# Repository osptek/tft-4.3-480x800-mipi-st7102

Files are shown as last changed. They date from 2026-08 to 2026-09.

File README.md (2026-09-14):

<p align="left">OSPTEK</p>

<h1 align="center">OSPTEK 4.3″ TFT 480×800（ST7102 · MIPI）</h1>

<p align="center"><b>TFT 模组 · MIPI · ST7102 · 多版本索引</b></p>

<p align="center"><a href="./README_EN.md">English</a> | 简体中文</p>

<p align="center">
  
  
  
  
</p>

## 目录

- [说明](#说明)
- [版本一览](#版本一览)
- [YDP430BT009-V1](#ydp430bt009-v1)
- [购买链接](#购买链接)
- [技术支持](#技术支持)

---

## 说明

本仓库收录 **4.3 寸 480×800 TFT（MIPI · ST7102）** 显示模组资料。

**根目录 README 为导航页**。下表可快速浏览各版本；点击「完整资料」进入 `versions/` 下对应**料号文件夹**（产品页、规格书、示例均在该目录内）。

规格标识（仓库名）：`tft-4.3-480x800-mipi-st7102`

---

## 版本一览

| 版本 | 宣传图 | 简介 | 完整资料 |
| ---- | --- | ---- | --- |
| YDP430BT009-V1 | YDP430BT009-V1 | [简介](#ydp430bt009-v1) | [完整资料](./versions/YDP430BT009-V1/) |

---

## YDP430BT009-V1

<p align="center">YDP430BT009-V1</p>

**说明：** 带触摸（ST7123）。

完整产品页、规格书与示例：[versions/YDP430BT009-V1/](./versions/YDP430BT009-V1/)

---

## 购买链接

<p align="center">
  
  &nbsp;&nbsp;
  
</p>

**国内（淘宝）**

- 店铺：[鱼鹰光电工厂店](https://shop110742373.taobao.com/)

**海外（AliExpress）**

- 店铺：[OSPTEK Official Store](https://www.aliexpress.com/store/1105701619)

---

## 技术支持

- 技术支持 / 产品咨询：<luyu@osptek.com>
- QQ 技术交流群：**985881096**
- 公司官网：<https://osptek.com/>
- 有任何问题，都可以在本仓库 Issues 中提问

---

<p align="center"><sub>© 2026 OSPTEK 鱼鹰光电 · 本仓库资料采用 CC BY 4.0 许可</sub></p>

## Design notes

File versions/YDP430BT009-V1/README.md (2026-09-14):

<p align="left">OSPTEK</p>

<h1 align="center">OSPTEK 4.3″ TFT 480×800（ST7102 · MIPI）</h1>

<p align="center"><b>触摸 TFT 模组 · MIPI DSI · ST7102</b></p>

<p align="center"><a href="./README_EN.md">English</a> | 简体中文 · <a href="../../README.md">规格族索引</a></p>

<p align="center">
  
  
  
  
</p>

<p align="center">OSPTEK 4.3 寸 480×800 TFT MIPI 模组（ST7102）宣传图</p>

## 目录

- [产品简介](#产品简介)
- [规格参数](#规格参数)
- [示例工程](#示例工程)
- [仓库结构](#仓库结构)
- [相关资料](#相关资料)
- [购买链接](#购买链接)
- [技术支持](#技术支持)

---

## 产品简介

OSPTEK **4.3 寸 480×800 TFT** 是一款 **MIPI DSI** 接口彩色显示模组，显示驱动为 **ST7102**，触摸驱动为 **ST7123**。适合中小尺寸 HMI、手持终端与竖屏信息面板等场景。

规格标识（仓库名）：`tft-4.3-480x800-mipi-st7102`

当前模组版本：**YDP430BT009-V1**。电气与外形细节以 [`docs/YDP_430_BT_009_V1_a418b8470b.pdf`](./docs/YDP_430_BT_009_V1_a418b8470b.pdf) 为准。

## 规格参数

| 项目 | 规格 |
| ---- | ---- |
| 尺寸 | 4.3 英寸 |
| 类型 | TFT（彩色） |
| 分辨率 | 480×800 |
| 接口 | MIPI DSI |
| 驱动 IC | ST7102 |
| 触摸驱动 | ST7123 |

> 完整外形尺寸、FPC 定义、供电与时序以产品规格书 / 驱动手册为准。

## 示例工程

| 说明 | 路径 |
| ---- | ---- |
| ESP32-P4 · ST7102 MIPI + esp-lvgl-port / LVGL9 | [`examples/esp32p4-idf5_st7102-mipi_esp-lvgl-port_lvgl9/`](./examples/esp32p4-idf5_st7102-mipi_esp-lvgl-port_lvgl9/) |
| ESP32-P4 · 防撕裂 LVGL 演示 | [`examples/with-te/p4-idf_st7102-mipi_lvgl-common-demo/`](./examples/with-te/p4-idf_st7102-mipi_lvgl-common-demo/) |
| ESP32-P4 · ST7102 MIPI + SC2336 摄像头预览 | [`examples/camera/esp32p4-idf5_st7102-mipi-dsi_sc2336-mipi-csi_video-lcd-display/`](./examples/camera/esp32p4-idf5_st7102-mipi-dsi_sc2336-mipi-csi_video-lcd-display/) |
| Linux · RK3566 设备树 + ST7123 触摸参考 | [`examples/linux/`](./examples/linux/) |
| Raspberry Pi 5 · ST7102 480×800 面板驱动 / DT overlay（仅显示） | [`examples/rpi5-panel-st7102-480x800/`](./examples/rpi5-panel-st7102-480x800/) |
| Raspberry Pi 5 · ST7102 显示 + ST7123 触摸 / DT overlay | [`examples/rpi5-panel-st7102-st7123-480x800/`](./examples/rpi5-panel-st7102-st7123-480x800/) |
| Raspberry Pi 5 · ST7102 + ST7123 · LVGL（DRM + EVDEV） | [`examples/rpi5-lvgl-st7102-st7123-480x800/`](./examples/rpi5-lvgl-st7102-st7123-480x800/) |

## 仓库结构

```text
tft-4.3-480x800-mipi-st7102/                                # 仓库根（导航见 ../../README.md）
└── versions/
    └── YDP430BT009-V1/                                # 本料号完整资料
        ├── README.md
        ├── README_EN.md
        ├── images/
        ├── docs/
        └── examples/
```

## 相关资料

### 本产品资料

| 资料 | 链接 |
| ---- | ---- |
| 产品规格书（YDP430BT009-V1） | [`docs/YDP_430_BT_009_V1_a418b8470b.pdf`](./docs/YDP_430_BT_009_V1_a418b8470b.pdf) |
| 外形图（YDP430BT009-V1） | [`docs/YDP430BT009-V1_外形图.pdf`](./docs/YDP430BT009-V1_%E5%A4%96%E5%BD%A2%E5%9B%BE.pdf) |
| 3D 图纸（YDP430BT009-V1） | [`docs/YDP430BT009-V1.dwg`](./docs/YDP430BT009-V1.dwg) |
| 3D 模型（STEP） | [`docs/YDP430BT009-V1.step`](./docs/YDP430BT009-V1.step) |
| 驱动 IC 数据手册（ST7102） | [`docs/ST7102_Datasheet_V0.22.pdf`](./docs/ST7102_Datasheet_V0.22.pdf) |
| 初始化序列（C） | [`docs/GX09C_ST7102+BOE4.3_2LANE_90HZ.c`](./docs/GX09C_ST7102+BOE4.3_2LANE_90HZ.c) |
| 时序配置参考图（90 Hz） | [`docs/RGB_Output_Timing_90Hz.jpg`](./docs/RGB_Output_Timing_90Hz.jpg) |
| 4.3 寸 LCD 转接板原理图 | [`docs/4.3寸LCD转接板V1.0.pdf`](./docs/4.3%E5%AF%B8LCD%E8%BD%AC%E6%8E%A5%E6%9D%BFV1.0.pdf) |

### 示例工程

- [ESP32-P4 ST7102 MIPI + LVGL9](./examples/esp32p4-idf5_st7102-mipi_esp-lvgl-port_lvgl9/)
- [ESP32-P4 防撕裂 LVGL 演示](./examples/with-te/p4-idf_st7102-mipi_lvgl-common-demo/)
- [ESP32-P4 ST7102 MIPI + SC2336 摄像头预览](./examples/camera/esp32p4-idf5_st7102-mipi-dsi_sc2336-mipi-csi_video-lcd-display/)
- [Linux RK3566 + ST7123 参考](./examples/linux/)
- [Raspberry Pi 5 ST7102 面板（仅显示）](./examples/rpi5-panel-st7102-480x800/)
- [Raspberry Pi 5 ST7102 显示 + ST7123 触摸](./examples/rpi5-panel-st7102-st7123-480x800/)
- [Raspberry Pi 5 ST7102 + ST7123 · LVGL](./examples/rpi5-lvgl-st7102-st7123-480x800/)

## 购买链接

<p align="center">
  
  &nbsp;&nbsp;
  
</p>

**国内（淘宝）**

- 店铺：[鱼鹰光电工厂店](https://shop110742373.taobao.com/)

**海外（AliExpress）**

- 店铺：[OSPTEK Official Store](https://www.aliexpress.com/store/1105701619)

## 技术支持

- 技术支持 / 产品咨询：<luyu@osptek.com>
- QQ 技术交流群：**985881096**
- 公司官网：<https://osptek.com/>
- 有任何问题，都可以在本仓库 Issues 中提问

---

<p align="center"><sub>© 2026 OSPTEK 鱼鹰光电 · 本仓库资料采用 CC BY 4.0 许可</sub></p>

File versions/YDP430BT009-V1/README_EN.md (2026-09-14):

<p align="left">OSPTEK</p>

<h1 align="center">OSPTEK 4.3″ TFT 480×800 (ST7102 · MIPI)</h1>

<p align="center"><b>Touch TFT module · MIPI DSI · ST7102</b></p>

<p align="center"><a href="./README.md">简体中文</a> | English · <a href="../../README_EN.md">Family index</a></p>

<p align="center">
  
  
  
  
</p>

<p align="center">OSPTEK 4.3" 480×800 TFT MIPI module (ST7102) product image</p>

## Contents

- [Overview](#overview)
- [Specifications](#specifications)
- [Sample projects](#sample-projects)
- [Repository layout](#repository-layout)
- [Resources](#resources)
- [Buy](#buy)
- [Support](#support)

---

## Overview

OSPTEK **4.3″ 480×800 TFT** is a **MIPI DSI** color display module driven by **ST7102**, with touch controller **ST7123**. It suits compact HMI, handheld terminals, and portrait info panels.

Spec ID (repository name): `tft-4.3-480x800-mipi-st7102`

Current module version: **YDP430BT009-V1**. Electrical and mechanical details follow [`docs/YDP_430_BT_009_V1_a418b8470b.pdf`](./docs/YDP_430_BT_009_V1_a418b8470b.pdf).

## Specifications

| Item | Spec |
| ---- | ---- |
| Size | 4.3 inch |
| Type | TFT (color) |
| Resolution | 480×800 |
| Interface | MIPI DSI |
| Driver IC | ST7102 |
| Touch IC | ST7123 |

> Full outline, FPC definition, power, and timing follow the product datasheet / driver IC datasheet.

## Sample projects

| Description | Path |
| ---- | ---- |
| ESP32-P4 · ST7102 MIPI + esp-lvgl-port / LVGL9 | [`examples/esp32p4-idf5_st7102-mipi_esp-lvgl-port_lvgl9/`](./examples/esp32p4-idf5_st7102-mipi_esp-lvgl-port_lvgl9/) |
| ESP32-P4 · tear-related LVGL demo | [`examples/with-te/p4-idf_st7102-mipi_lvgl-common-demo/`](./examples/with-te/p4-idf_st7102-mipi_lvgl-common-demo/) |
| ESP32-P4 · ST7102 MIPI + SC2336 camera preview | [`examples/camera/esp32p4-idf5_st7102-mipi-dsi_sc2336-mipi-csi_video-lcd-display/`](./examples/camera/esp32p4-idf5_st7102-mipi-dsi_sc2336-mipi-csi_video-lcd-display/) |
| Linux · RK3566 device tree + ST7123 touch reference | [`examples/linux/`](./examples/linux/) |
| Raspberry Pi 5 · ST7102 480×800 panel / DT overlay (display only) | [`examples/rpi5-panel-st7102-480x800/`](./examples/rpi5-panel-st7102-480x800/) |
| Raspberry Pi 5 · ST7102 display + ST7123 touch / DT overlay | [`examples/rpi5-panel-st7102-st7123-480x800/`](./examples/rpi5-panel-st7102-st7123-480x800/) |
| Raspberry Pi 5 · ST7102 + ST7123 · LVGL (DRM + EVDEV) | [`examples/rpi5-lvgl-st7102-st7123-480x800/`](./examples/rpi5-lvgl-st7102-st7123-480x800/) |

## Repository layout

```text
tft-4.3-480x800-mipi-st7102/                                # repo root (nav: ../../README_EN.md)
└── versions/
    └── YDP430BT009-V1/                                # full materials for this part number
        ├── README.md
        ├── README_EN.md
        ├── images/
        ├── docs/
        └── examples/
```

## Resources

### Product files

| Resource | Link |
| ---- | ---- |
| Product datasheet (YDP430BT009-V1) | [`docs/YDP_430_BT_009_V1_a418b8470b.pdf`](./docs/YDP_430_BT_009_V1_a418b8470b.pdf) |
| Outline drawing (YDP430BT009-V1) | [`docs/YDP430BT009-V1_外形图.pdf`](./docs/YDP430BT009-V1_%E5%A4%96%E5%BD%A2%E5%9B%BE.pdf) |
| 3D drawing (YDP430BT009-V1) | [`docs/YDP430BT009-V1.dwg`](./docs/YDP430BT009-V1.dwg) |
| 3D model (STEP) | [`docs/YDP430BT009-V1.step`](./docs/YDP430BT009-V1.step) |
| Driver IC datasheet (ST7102) | [`docs/ST7102_Datasheet_V0.22.pdf`](./docs/ST7102_Datasheet_V0.22.pdf) |
| Init sequence (C) | [`docs/GX09C_ST7102+BOE4.3_2LANE_90HZ.c`](./docs/GX09C_ST7102+BOE4.3_2LANE_90HZ.c) |
| Timing reference (90 Hz) | [`docs/RGB_Output_Timing_90Hz.jpg`](./docs/RGB_Output_Timing_90Hz.jpg) |
| 4.3″ LCD adapter schematic | [`docs/4.3寸LCD转接板V1.0.pdf`](./docs/4.3%E5%AF%B8LCD%E8%BD%AC%E6%8E%A5%E6%9D%BFV1.0.pdf) |

### Samples

- [ESP32-P4 ST7102 MIPI + LVGL9](./examples/esp32p4-idf5_st7102-mipi_esp-lvgl-port_lvgl9/)
- [ESP32-P4 tear-related LVGL demo](./examples/with-te/p4-idf_st7102-mipi_lvgl-common-demo/)
- [ESP32-P4 ST7102 MIPI + SC2336 camera preview](./examples/camera/esp32p4-idf5_st7102-mipi-dsi_sc2336-mipi-csi_video-lcd-display/)
- [Linux RK3566 + ST7123 reference](./examples/linux/)
- [Raspberry Pi 5 ST7102 panel (display only)](./examples/rpi5-panel-st7102-480x800/)
- [Raspberry Pi 5 ST7102 display + ST7123 touch](./examples/rpi5-panel-st7102-st7123-480x800/)
- [Raspberry Pi 5 ST7102 + ST7123 · LVGL](./examples/rpi5-lvgl-st7102-st7123-480x800/)

## Buy

<p align="center">
  
  &nbsp;&nbsp;
  
</p>

**Overseas (AliExpress)**

- Store: [OSPTEK Official Store](https://www.aliexpress.com/store/1105701619)

**China (Taobao)**

- Store: [鱼鹰光电工厂店](https://shop110742373.taobao.com/)

## Support

- Technical support / product inquiry: <luyu@osptek.com>
- QQ group (China): **985881096**
- Website: <https://osptek.com/>
- Feel free to open an Issue in this repository if you have any questions

---

<p align="center"><sub>© 2026 OSPTEK · Materials in this repository are licensed under CC BY 4.0</sub></p>

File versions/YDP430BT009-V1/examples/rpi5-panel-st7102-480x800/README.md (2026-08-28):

# Raspberry Pi 5 · ST7102 480×800（仅显示）

本目录为 **YDP430BT009-V1** 在 Raspberry Pi 5 上的 **仅显示** 内核模块与 DT overlay 示例（无触摸）。

本目录文件：

| 文件 | 说明 |
| ---- | ---- |
| `panel-st7102-480x800.c` | ST7102 DRM panel 驱动 |
| `Makefile` | 内核模块编译 |
| `vc4-kms-dsi-st7102-480x800.dts` | DSI overlay |

---

# 1. 准备工作

```bash
sudo apt update
sudo apt install build-essential linux-headers-$(uname -r) device-tree-compiler
```

将本目录拷到树莓派后进入该目录（以下命令默认在本目录执行）。

# 2. 编译内核模块

```bash
make clean
make
```

# 3. 编译并安装 Overlay / 模块

```bash
dtc -@ -I dts -O dtb -o vc4-kms-dsi-st7102-480x800.dtbo vc4-kms-dsi-st7102-480x800.dts
sudo cp vc4-kms-dsi-st7102-480x800.dtbo /boot/firmware/overlays/
sudo mkdir -p /lib/modules/$(uname -r)/kernel/drivers/gpu/drm/panel/
sudo cp panel-st7102-480x800.ko /lib/modules/$(uname -r)/kernel/drivers/gpu/drm/panel/
sudo depmod -a
```

> Overlay 必须使用 `dtc -@`，否则符号修复可能失败，DTO 无法正确加载。

# 4. 启用

编辑 `/boot/firmware/config.txt`：

```bash
sudo nano /boot/firmware/config.txt
```

添加（或确认）如下配置：

```text
# 关闭自动检测，避免和手动 overlay 冲突
display_auto_detect=0

dtoverlay=vc4-kms-v3d

dtoverlay=vc4-kms-dsi-st7102-480x800

# 忽略官方 LCD
ignore_lcd=1
```

重启：

```bash
sudo reboot
```

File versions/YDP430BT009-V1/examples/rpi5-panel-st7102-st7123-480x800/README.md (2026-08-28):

# Raspberry Pi 5 · ST7102 显示 + ST7123 触摸（480×800）

本目录为 **YDP430BT009-V1** 在 Raspberry Pi 5 上的 **显示 + 触摸** 内核模块与 DT overlay 示例。

本目录文件：

| 文件 | 说明 |
| ---- | ---- |
| `panel-st7102-480x800.c` | ST7102 DRM panel 驱动 |
| `st7123_touch.c` | ST7123 触摸驱动 |
| `Makefile` | 内核模块编译 |
| `vc4-kms-dsi-st7102-480x800-st7123-overlay.dts` | DSI + 触摸 overlay |

若还需跑 LVGL，见同级目录 [`../rpi5-lvgl-st7102-st7123-480x800/`](../rpi5-lvgl-st7102-st7123-480x800/)。

---

# 1. 准备工作

```bash
sudo apt update
sudo apt install build-essential linux-headers-$(uname -r) device-tree-compiler
```

将本目录拷到树莓派后进入该目录（以下命令默认在本目录执行）。

# 2. 编译内核模块

```bash
make clean
make
```

# 3. 安装模块

```bash
sudo mkdir -p /lib/modules/$(uname -r)/kernel/drivers/gpu/drm/panel/
sudo cp panel-st7102-480x800.ko /lib/modules/$(uname -r)/kernel/drivers/gpu/drm/panel/

sudo mkdir -p /lib/modules/$(uname -r)/kernel/drivers/input/touchscreen/
sudo cp st7123_touch.ko /lib/modules/$(uname -r)/kernel/drivers/input/touchscreen/

sudo depmod -a
```

设置开机自动加载模块：编辑 `/etc/modules`，末尾加上：

```text
panel-st7102-480x800
st7123_touch
```

# 4. 编译并安装 Overlay

```bash
dtc -@ -I dts -O dtb -o vc4-kms-dsi-st7102-480x800-st7123-overlay.dtbo vc4-kms-dsi-st7102-480x800-st7123-overlay.dts
sudo cp vc4-kms-dsi-st7102-480x800-st7123-overlay.dtbo /boot/firmware/overlays/
```

> Overlay 必须使用 `dtc -@`，否则符号修复可能失败，DTO 无法正确加载。

# 5. 启用

编辑 `/boot/firmware/config.txt`：

```bash
sudo nano /boot/firmware/config.txt
```

添加（或确认）：

```text
# 关闭自动检测，避免和手动 overlay 冲突
display_auto_detect=0

dtoverlay=vc4-kms-v3d

# 启用 ST7102 显示与 ST7123 触控 Overlay
dtoverlay=vc4-kms-dsi-st7102-480x800-st7123-overlay

# 忽略官方 LCD
ignore_lcd=1
```

重启：

```bash
sudo reboot
```

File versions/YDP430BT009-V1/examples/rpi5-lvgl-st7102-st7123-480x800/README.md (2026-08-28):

# Raspberry Pi 5 · ST7102 + ST7123 · LVGL（480×800）

本目录为 **YDP430BT009-V1** 在 Raspberry Pi 5 上跑 **LVGL（lv_port_linux / DRM + EVDEV）** 的参考：含显示/触摸内核模块、DT overlay，以及替换 `lv_port_linux` 用的 `main.c`。

本目录文件：

| 文件 | 说明 |
| ---- | ---- |
| `panel-st7102-480x800.c` | ST7102 DRM panel 驱动 |
| `st7123_touch.c` | ST7123 触摸驱动 |
| `Makefile` | 内核模块编译 |
| `vc4-kms-dsi-st7102-480x800-st7123-overlay.dts` | DSI + 触摸 overlay |
| `main.c` | 拷入 `lv_port_linux/src/main.c` 的参考实现（默认 480×800 / DRM / EVDEV） |

仅点亮显示+触摸、不跑 LVGL 时，也可只用同级 [`../rpi5-panel-st7102-st7123-480x800/`](../rpi5-panel-st7102-st7123-480x800/)。

---

# 1. 准备工作

```bash
sudo apt update
sudo apt install build-essential linux-headers-$(uname -r) device-tree-compiler
```

将本目录拷到树莓派后进入该目录。

# 2. 编译并安装内核模块

```bash
make clean
make

sudo mkdir -p /lib/modules/$(uname -r)/kernel/drivers/gpu/drm/panel/
sudo cp panel-st7102-480x800.ko /lib/modules/$(uname -r)/kernel/drivers/gpu/drm/panel/

sudo mkdir -p /lib/modules/$(uname -r)/kernel/drivers/input/touchscreen/
sudo cp st7123_touch.ko /lib/modules/$(uname -r)/kernel/drivers/input/touchscreen/

sudo depmod -a
```

开机自动加载：编辑 `/etc/modules`，末尾加上：

```text
panel-st7102-480x800
st7123_touch
```

# 3. 编译并安装 Overlay

```bash
dtc -@ -I dts -O dtb -o vc4-kms-dsi-st7102-480x800-st7123-overlay.dtbo vc4-kms-dsi-st7102-480x800-st7123-overlay.dts
sudo cp vc4-kms-dsi-st7102-480x800-st7123-overlay.dtbo /boot/firmware/overlays/
```

> Overlay **必须**使用 `dtc -@`，否则符号修复可能失败，DTO 无法正确加载。

# 4. 启用 Overlay

编辑 `/boot/firmware/config.txt`：

```bash
sudo nano /boot/firmware/config.txt
```

```text
# 关闭自动检测，避免和手动 overlay 冲突
display_auto_detect=0

dtoverlay=vc4-kms-v3d

# 启用 ST7102 显示与 ST7123 触控 Overlay
dtoverlay=vc4-kms-dsi-st7102-480x800-st7123-overlay

# 忽略官方 LCD
ignore_lcd=1
```

```bash
sudo reboot
```

# 5. 关闭桌面（若有桌面；无桌面可跳过）

## 5.1 开机进入命令行

```bash
sudo raspi-config
```

- `1 System Options` → `S5 Boot` → 选 **Console**
- `1 System Options` → `S6 Auto Login`：按需要选择是否自动登录
- 退出后重启：`sudo reboot`

## 5.2 用户组权限

```bash
sudo usermod -aG video,input,render $USER
```

重新登录或重启后生效。

# 6. 安装并运行 LVGL（lv_port_linux）

## 6.1 依赖

```bash
sudo apt install \
  build-essential cmake python3 python3-venv ninja-build \
  libsdl2-dev \
  libwayland-dev libxkbcommon-dev wayland-protocols \
  libx11-dev \
  libdrm-dev libgbm-dev \
  libevdev-dev \
  libwebp-dev \
  libegl-dev libgles-dev libgl-dev
```

## 6.2 克隆

```bash
git clone -b release/v9.5 --recursive https://github.com/lvgl/lv_port_linux.git
cd lv_port_linux
```

## 6.3 修改 `lv_conf.defaults`

```bash
nano lv_conf.defaults
```

确保包含（或等价配置）：

```text
LV_COLOR_DEPTH               32
LV_USE_LINUX_FBDEV           0
LV_USE_LINUX_DRM             1
LV_USE_LINUX_DRM_GBM_BUFFERS 0
LV_USE_EVDEV                 1
LV_USE_DEMO_WIDGETS          1
```

## 6.4 确认 DRM / 触摸节点

DRM（找 `status` 为 `connected` 的 DSI）：

```bash
for file in /sys/class/drm/card*-*/status; do echo "$file -> $(cat $file)"; done
```

示例：`/sys/class/drm/card2-DSI-2/status -> connected` → 设备节点多为 **`/dev/dri/card2`**（以实机为准）。

触摸：

```bash
cat /proc/bus/input/devices
```

查找 `ST7123` / `st7123`，在 `Handlers=` 中取 `eventN`，例如 `event5` → **`/dev/input/event5`**（以实机为准）。

## 6.5 替换 `src/main.c`

将本目录 `main.c` 拷到 `lv_port_linux/src/main.c`。若实机 DRM/触摸节点不是 `card2` / `event5`，请改 `main.c` 里：

- `LV_LINUX_DRM_CARD`
- `LV_LINUX_EVDEV_POINTER_DEVICE`

（默认分辨率已按 **480×800** 配置。）

## 6.6 若构建未生成 `lv_conf.h`

参见上游说明：<https://github.com/lvgl/lv_port_linux/issues/127>  
可在 CMake 中确保：

```cmake
find_package(Python3 REQUIRED COMPONENTS Interpreter)
```

## 6.7 编译与运行

```bash
cd lv_port_linux
cmake -B build -GNinja
cmake --build build
./build/bin/lvglsim
```

# 7. 开机自启（可选，systemd）

```bash
sudo nano /etc/systemd/system/lvgl.service
```

按实际用户与路径修改：

```ini
[Unit]
Description=LVGL Application Service
After=multi-user.target
Wants=multi-user.target

[Service]
Type=simple
User=pi
WorkingDirectory=/home/pi/lv_port_linux
ExecStart=/home/pi/lv_port_linux/build/bin/lvglsim
Restart=always
RestartSec=3
StandardOutput=journal
StandardError=journal

[Install]
WantedBy=multi-user.target
```

```bash
sudo usermod -aG render,video,input pi
sudo systemctl daemon-reload
sudo systemctl start lvgl.service
sudo systemctl status lvgl.service
# 确认正常后再：
sudo systemctl enable lvgl.service
```

常用：

```bash
sudo journalctl -u lvgl.service -f
sudo systemctl stop lvgl.service
sudo systemctl disable lvgl.service
```

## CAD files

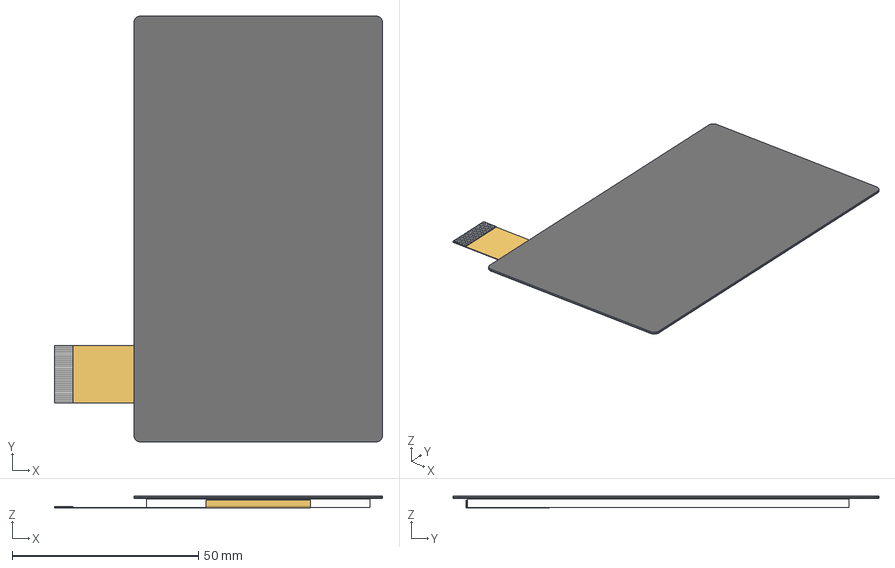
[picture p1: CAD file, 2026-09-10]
versions/YDP430BT009-V1/docs/YDP430BT009-V1.step
88.1 x 114.4 x 3.32 mm

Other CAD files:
versions/YDP430BT009-V1/docs/YDP430BT009-V1.dwg

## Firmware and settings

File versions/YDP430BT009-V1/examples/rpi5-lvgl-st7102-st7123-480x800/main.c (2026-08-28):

/*******************************************************************
 *
 * main.c - LVGL runner for Raspberry Pi 5 (Linux DRM + EVDEV)
 *
 * Modified for ST7102 DSI Screen (480x800) and Sitronix ST7123 Touch (/dev/input/event5)
 *
 ******************************************************************/
#include <unistd.h>
#include <pthread.h>
#include <stdio.h>
#include <stdlib.h>
#include <string.h>

#include "lvgl/lvgl.h"
#include "lvgl/demos/lv_demos.h"

#include "src/lib/driver_backends.h"
#include "src/lib/simulator_util.h"
#include "src/lib/simulator_settings.h"

/* Internal functions */
static void configure_simulator(int argc, char ** argv);
static void print_lvgl_version(void);
static void print_usage(void);

/* contains the name of the selected backend if user
 * has specified one on the command line */
static char * selected_backend;

/* Global simulator settings, defined in lv_linux_backend.c */
extern simulator_settings_t settings;


/**
 * @brief Print LVGL version
 */
static void print_lvgl_version(void)
{
    fprintf(stdout, "%d.%d.%d-%s\n",
            LVGL_VERSION_MAJOR,
            LVGL_VERSION_MINOR,
            LVGL_VERSION_PATCH,
            LVGL_VERSION_INFO);
}

/**
 * @brief Print usage information
 */
static void print_usage(void)
{
    fprintf(stdout,
            "\nlvglsim [-V] [-B] [-f] [-m] [-b backend_name] [-W window_width] [-H window_height] [-R rotation]\n\n");
    fprintf(stdout, "-V print LVGL version\n");
    fprintf(stdout, "-B list supported backends\n");
    fprintf(stdout, "-f fullscreen\n");
    fprintf(stdout, "-m maximize\n");
}

/**
 * @brief Configure simulator
 * @description process arguments received by the program to select
 * appropriate options
 * @param argc the count of arguments in argv
 * @param argv The arguments
 */
static void configure_simulator(int argc, char ** argv)
{
    int opt = 0;

    selected_backend = NULL;
    driver_backends_register();

    const char * env_w = getenv("LV_SIM_WINDOW_WIDTH");
    const char * env_h = getenv("LV_SIM_WINDOW_HEIGHT");
    
    /* 针对 480x800 ST7102 面板的默认分辨率配置 */
    settings.window_width = atoi(env_w ? env_w : "480");
    settings.window_height = atoi(env_h ? env_h : "800");

    /* Parse the command-line options. */
    while((opt = getopt(argc, argv, "b:fmW:H:R:BVh")) != -1) {
        switch(opt) {
            case 'h':
                print_usage();
                exit(EXIT_SUCCESS);
                break;
            case 'V':
                print_lvgl_version();
                exit(EXIT_SUCCESS);
                break;
            case 'B':
                driver_backends_print_supported();
                exit(EXIT_SUCCESS);
                break;
            case 'b':
                if(driver_backends_is_supported(optarg) == 0) {
                    die("error no such backend: %s\n", optarg);
                }
                selected_backend = strdup(optarg);
                break;
            case 'f':
                settings.fullscreen = true;
                break;
            case 'm':
                settings.maximize = true;
                break;
            case 'W':
                settings.window_width = atoi(optarg);
                break;
            case 'H':
                settings.window_height = atoi(optarg);
                break;
            case 'R':
                switch(atoi(optarg)) {
                    case 0:
                        settings.rotation = LV_DISPLAY_ROTATION_0;
                        break;
                    case 90:
                        settings.rotation = LV_DISPLAY_ROTATION_90;
                        break;
                    case 180:
                        settings.rotation = LV_DISPLAY_ROTATION_180;
                        break;
                    case 270:
                        settings.rotation = LV_DISPLAY_ROTATION_270;
                        break;
                    default:
                        LV_LOG_WARN("Invalid rotation angle. Valid angles are {0, 90, 180, 270}");
                        break;
                }
                break;
            case ':':
                print_usage();
                die("Option -%c requires an argument.\n", optopt);
                break;
            case '?':
                print_usage();
                die("Unknown option -%c.\n", optopt);
        }
    }
}

/**
 * @brief entry point
 * @description start a demo
 * @param argc the count of arguments in argv
 * @param argv The arguments
 */
int main(int argc, char ** argv)
{
    configure_simulator(argc, argv);

    /* Initialize LVGL. */
    lv_init();

    /* 1. 显式指定树莓派 5 默认后端的环境变量（如果没有通过 -b 指定） */
    if(selected_backend == NULL) {
        selected_backend = "DRM";
    }

    /* 2. 覆盖设置 DRM 显卡设备节点为树莓派 5 的 MIPI-DSI 卡节点 (/dev/dri/card2) */
    setenv("LV_LINUX_DRM_CARD", "/dev/dri/card2", 1);

    /* 初始化 DRM 显示后端 */
    if(driver_backends_init_backend(selected_backend) == -1) {
        die("Failed to initialize display backend");
    }

    if(settings.rotation) {
#if LV_USE_DRAW_NANOVG && LV_DRAW_TRANSFORM_USE_MATRIX
        lv_display_set_matrix_rotation(NULL, true);
#endif
        lv_display_set_rotation(NULL, settings.rotation);
    }

    /* 3. 配置 EVDEV 触摸设备节点为 Sitronix ST7123 的 /dev/input/event5 */
#if LV_USE_EVDEV
    setenv("LV_LINUX_EVDEV_POINTER_DEVICE", "/dev/input/event5", 1);
    if(driver_backends_init_backend("EVDEV") == -1) {
        die("Failed to initialize evdev");
    }
#endif

    /* 4. 创建及启动 Demo */
    lv_demo_widgets();

    /* 隐藏触摸设备绑定的鼠标光标/箭头 */
    lv_indev_t * indev = lv_indev_get_next(NULL);
    while(indev) {
        if(lv_indev_get_type(indev) == LV_INDEV_TYPE_POINTER) {
            lv_obj_t * cursor = lv_indev_get_cursor(indev);
            if(cursor) {
                lv_obj_add_flag(cursor, LV_OBJ_FLAG_HIDDEN);
            }
        }
        indev = lv_indev_get_next(indev);
    }

    /* 5. 进入主运行循环 */
    driver_backends_run_loop();

    return 0;
}

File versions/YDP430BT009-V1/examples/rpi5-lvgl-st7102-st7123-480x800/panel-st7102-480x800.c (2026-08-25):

/*
 * ST7102 480x800 2-Lane MIPI-DSI Panel Driver for Raspberry Pi 5
 *
 * This example is from the open-source sharing by engineers of Yuying Optoelectronics (鱼鹰光电)
 * on Github.com/osptek. Welcome to provide improvement suggestions.
 *
 * 本例程来源于鱼鹰光电的工程师的开源分享 Github.com/osptek，欢迎提出改进意见
 */
 
#include <drm/drm_mipi_dsi.h>
#include <drm/drm_modes.h>
#include <drm/drm_panel.h>
#include <linux/backlight.h>
#include <linux/delay.h>
#include <linux/gpio/consumer.h>
#include <linux/module.h>
#include <linux/of.h>
#include <video/mipi_display.h>

struct power_on_timing {
	unsigned long post_reset;
	unsigned long reset_low;
	unsigned long after_reset;
	unsigned long slpout;
};

struct st7102_desc {
	const struct drm_display_mode *mode;
	unsigned int lanes;
	unsigned long flags;
	enum mipi_dsi_pixel_format format;
	int (*init_sequence)(struct mipi_dsi_device *dsi);
	const struct power_on_timing *pwr_timing;
	bool do_sw_reset;
};

struct st7102 {
	struct drm_panel panel;
	struct mipi_dsi_device *dsi;
	const struct st7102_desc *desc;
	struct gpio_desc *reset;
	enum drm_panel_orientation orientation;
};

static inline struct st7102 *to_st7102(struct drm_panel *panel)
{
	return container_of(panel, struct st7102, panel);
}

static int st7102_480x800_init_sequence(struct mipi_dsi_device *dsi)
{
	struct mipi_dsi_multi_context ctx = { .dsi = dsi };

	mipi_dsi_dcs_write_seq_multi(&ctx, 0x99, 0x71, 0x02, 0xa2);
	mipi_dsi_dcs_write_seq_multi(&ctx, 0x99, 0x71, 0x02, 0xa3);
	mipi_dsi_dcs_write_seq_multi(&ctx, 0x99, 0x71, 0x02, 0xa4);
	mipi_dsi_dcs_write_seq_multi(&ctx, 0xB0, 0x22, 0x57, 0x1E, 0x61, 0x2F, 0x57, 0x61);
	mipi_dsi_dcs_write_seq_multi(&ctx, 0xB7, 0x64, 0x64);
	mipi_dsi_dcs_write_seq_multi(&ctx, 0xBF, 0xB4, 0xB4);

	mipi_dsi_dcs_write_seq_multi(&ctx, 0xC8,
		0x00, 0x00, 0x13, 0x24, 0x44, 0x00, 0x74, 0x03, 0xB8, 0x04,
		0x11, 0x16, 0x08, 0x86, 0x04, 0x21, 0xD3, 0x02, 0x10, 0x0F,
		0x22, 0x4D, 0x0E, 0x90, 0x09, 0x32, 0xF0, 0x0B, 0x40, 0x0E,
		0xF3, 0x7D, 0x0E, 0xA9, 0xBF, 0x03, 0xC4);

	mipi_dsi_dcs_write_seq_multi(&ctx, 0xC9,
		0x00, 0x00, 0x13, 0x24, 0x44, 0x00, 0x74, 0x03, 0xB8, 0x04,
		0x11, 0x16, 0x08, 0x86, 0x04, 0x21, 0xD3, 0x02, 0x10, 0x0F,
		0x22, 0x4D, 0x0E, 0x90, 0x09, 0x32, 0xF0, 0x0B, 0x40, 0x0E,
		0xF3, 0x7D, 0x0E, 0xA9, 0xBF, 0x03, 0xC4);

	mipi_dsi_dcs_write_seq_multi(&ctx, 0xD7, 0x10, 0x0C, 0x36, 0x19, 0x90, 0x90);

	mipi_dsi_dcs_write_seq_multi(&ctx, 0xA3,
		0x51, 0x03, 0x80, 0xCF, 0x44, 0x00, 0x00, 0x00, 0x00, 0x04,
		0x78, 0x78, 0x00, 0x1A, 0x00, 0x45, 0x05, 0x00, 0x00, 0x00,
		0x00, 0x46, 0x00, 0x00, 0x02, 0x20, 0x52, 0x00, 0x05, 0x00,
		0x00, 0xFF);

	mipi_dsi_dcs_write_seq_multi(&ctx, 0xA6,
		0x02, 0x00, 0x24, 0x55, 0x35, 0x00, 0x38, 0x00, 0x78, 0x78,
		0x00, 0x24, 0x55, 0x36, 0x00, 0x37, 0x00, 0x78, 0x78, 0x02,
		0xAC, 0x51, 0x3A, 0x00, 0x00, 0x00, 0x78, 0x78, 0x03, 0xAC,
		0x21, 0x00, 0x04, 0x00, 0x00, 0x78, 0x78, 0x3e, 0x00, 0x06,
		0x00, 0x00, 0x00, 0x00);

	mipi_dsi_dcs_write_seq_multi(&ctx, 0xA7,
		0x19, 0x19, 0x00, 0x64, 0x40, 0x07, 0x16, 0x40, 0x00, 0x04,
		0x03, 0x78, 0x78, 0x00, 0x64, 0x40, 0x25, 0x34, 0x00, 0x00,
		0x02, 0x01, 0x78, 0x78, 0x00, 0x64, 0x40, 0x4B, 0x5A, 0x00,
		0x00, 0x02, 0x01, 0x78, 0x78, 0x00, 0x24, 0x40, 0x69, 0x78,
		0x00, 0x00, 0x00, 0x00, 0x78, 0x78, 0x00, 0x44);

	mipi_dsi_dcs_write_seq_multi(&ctx, 0xAC,
		0x08, 0x0A, 0x11, 0x00, 0x13, 0x03, 0x1B, 0x18, 0x06, 0x1A,
		0x19, 0x1B, 0x1B, 0x1B, 0x18, 0x1B, 0x09, 0x0B, 0x10, 0x02,
		0x12, 0x01, 0x1B, 0x18, 0x06, 0x1A, 0x19, 0x1B, 0x1B, 0x1B,
		0x18, 0x1B, 0xFF, 0x67, 0xFF, 0x67, 0x00);

	mipi_dsi_dcs_write_seq_multi(&ctx, 0xAD, 0xCC, 0x40, 0x46, 0x11, 0x04, 0x78, 0x78);

	mipi_dsi_dcs_write_seq_multi(&ctx, 0xE8,
		0x30, 0x07, 0x00, 0x94, 0x94, 0x9C, 0x00, 0xE2, 0x04, 0x00,
		0x00, 0x00, 0x00, 0xEF);

	mipi_dsi_dcs_write_seq_multi(&ctx, 0xE7,
		0x8B, 0x3C, 0x00, 0x0C, 0xF0, 0x5D, 0x00, 0x5D, 0x00, 0x5D,
		0x00, 0x5D, 0x00, 0xFF, 0x00, 0x08, 0x7B, 0x00, 0x00, 0xC8,
		0x6A, 0x5A, 0x08, 0x1A, 0x3C, 0x00, 0x81, 0x01, 0xCC, 0x01,
		0x7F, 0xF0, 0x22);

	/* 退出 Sleep 状态，激活 TDDI 底板 */
	mipi_dsi_dcs_write_seq_multi(&ctx, 0x11);
	msleep(600);

	/* 开启显示 */
	mipi_dsi_dcs_write_seq_multi(&ctx, 0x29);
	msleep(120);

	return ctx.accum_err;
}

static int st7102_prepare(struct drm_panel *panel)
{
	struct st7102 *st7102 = to_st7102(panel);
	struct mipi_dsi_multi_context ctx = { .dsi = st7102->dsi };

	if (st7102->reset) {
		gpiod_set_value_cansleep(st7102->reset, 1);
		msleep(st7102->desc->pwr_timing->post_reset);
		gpiod_set_value_cansleep(st7102->reset, 0);
		msleep(st7102->desc->pwr_timing->reset_low);
		gpiod_set_value_cansleep(st7102->reset, 1);
		msleep(st7102->desc->pwr_timing->after_reset);
	}

	if (st7102->desc->do_sw_reset) {
		mipi_dsi_dcs_soft_reset_multi(&ctx);
		msleep(st7102->desc->pwr_timing->after_reset);
	}

	if (st7102->desc->init_sequence) {
		int ret = st7102->desc->init_sequence(st7102->dsi);
		if (ret)
			return ret;
	}

	return ctx.accum_err;
}

static int st7102_enable(struct drm_panel *panel)
{
	struct mipi_dsi_multi_context ctx = { .dsi = to_mipi_dsi_device(panel->dev) };
	mipi_dsi_dcs_set_display_on_multi(&ctx);
	return ctx.accum_err;
}

static int st7102_disable(struct drm_panel *panel)
{
	struct mipi_dsi_multi_context ctx = { .dsi = to_mipi_dsi_device(panel->dev) };
	mipi_dsi_dcs_set_display_off_multi(&ctx);
	return ctx.accum_err;
}

static int st7102_unprepare(struct drm_panel *panel)
{
	struct st7102 *st7102 = to_st7102(panel);
	struct mipi_dsi_multi_context ctx = { .dsi = st7102->dsi };

	mipi_dsi_dcs_enter_sleep_mode_multi(&ctx);
	if (st7102->reset)
		gpiod_set_value_cansleep(st7102->reset, 0);

	return ctx.accum_err;
}

static int st7102_get_modes(struct drm_panel *panel, struct drm_connector *connector)
{
	struct st7102 *st7102 = to_st7102(panel);
	struct drm_display_mode *mode;

	mode = drm_mode_duplicate(connector->dev, st7102->desc->mode);
	if (!mode)
		return -ENOMEM;

	drm_mode_set_name(mode);
	drm_mode_probed_add(connector, mode);

	connector->display_info.width_mm = mode->width_mm;
	connector->display_info.height_mm = mode->height_mm;

	drm_connector_set_orientation_from_panel(connector, panel);
	return 1;
}

static enum drm_panel_orientation st7102_get_orientation(struct drm_panel *panel)
{
	return to_st7102(panel)->orientation;
}

static const struct drm_panel_funcs st7102_funcs = {
	.prepare = st7102_prepare,
	.enable = st7102_enable,
	.disable = st7102_disable,
	.unprepare = st7102_unprepare,
	.get_modes = st7102_get_modes,
	.get_orientation = st7102_get_orientation,
};

static const struct drm_display_mode st7102_mode = {
	.clock = 37800,

	.hdisplay = 480,
	.hsync_start = 480 + 40,
	.hsync_end   = 480 + 40 + 2,
	.htotal      = 480 + 40 + 2 + 40,

	.vdisplay = 800,
	.vsync_start = 800 + 310,
	.vsync_end   = 800 + 310 + 2,
	.vtotal      = 800 + 310 + 2 + 10,

	.width_mm = 56,
	.height_mm = 93,

	.type = DRM_MODE_TYPE_DRIVER | DRM_MODE_TYPE_PREFERRED,
};
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

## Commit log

2026-08-25 docs(examples): add Raspberry Pi 5 ST7102 panel packages
    - add display-only and display+touch overlays under YDP430BT009-V1
    - link both packages in Chinese and English product READMEs
2026-08-28 docs(examples): add RPi5 LVGL sample and refresh ST7102 panel docs
    - add rpi5-lvgl-st7102-st7123-480x800 with panel, touch, overlay, and main.c
    - align display+touch overlay filename with stack package
    - fix dtc -@ notes and bilingual sample links on YDP430BT009-V1
    [main.c, panel-st7102-480x800.c, st7123_touch.c]
2026-09-08 docs(module): replace YDP430BT009-V1 3D drawing
    [YDP430B009-V1.dwg, YDP430BT009-V1.dwg]
2026-09-10 docs(module): add YDP430BT009-V1 STEP model
    [YDP430BT009-V1.step]
